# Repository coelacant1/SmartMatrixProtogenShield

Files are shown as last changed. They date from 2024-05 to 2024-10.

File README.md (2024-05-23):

# SmartMatrixProtogenShield
SmartMatrix SmartLED Shield breakout for Protogen hardware

## General Information
The SmartLED Shield for the Teensy 4 is used as the backbone to this design. This allows you to use open-source code to easily implement if you decide against using ProtoTracer to display graphics on your Protogen!

The following information is pulled directly from their Crowd Supply page as a means of maintaining a local copy in case they take the posting down:
[SmartLED Shield for Teensy 4](https://www.crowdsupply.com/pixelmatix/smartled-shield-for-teensy-4)

## Controller Breakout

### Information
The controller breakout provides sensor connectivity, power distribution, and indication methods for power.

## Bill of Materials

| **RefDes** | **Value** | **Footprint** | **Quantity** | **Description** |
|---|---|---|---|---|
| C1-C4 | 22µF | SMD 0805 | 4 | Power filtering capacitors |
| R1,R2,R5,R6 | 10KΩ | SMD 0805 | 4 | Pull-up resistors |
| R3,R4 | 470Ω | SMD 0805 | 2 | APA102 impedance matching resistors |
| LED1-2 | | SMD 0805 | 2 | Indicator LEDs. Type does not matter. |
| LEDPWR, BCKPWR | AMASS XT30U-F | Through-Hole  | 2 | Power in and out |
| I2C1-4 | JST S4B-XH-A  | Through-Hole  | 4 | I2C Devices |

## Power Setup

### Powering the Teensy 4.0 for Programming
For programming the Teensy 4.0, the bottom VIN from VUSB trace needs to be cut to not provide power to the LED boards and cause damage while programming.

### Powering the Controller for Usage
To use the controller, 5V must be provided to the XT30 connector. Make sure you follow the standards for the XT30 polarity!

## Sensors/Peripherals

### Boop Sensor (APDS-9960)
The APDS-9960 is a Time-of-Flight sensor that uses an IR light to measure the distance to the object in front of it using the I2C communication protocol. This can be connected on either the Teensy I2C breakout or the ESP32 I2C breakout. The following picture shows the recommended location for the device:

### MAX9814 Microphone
The MAX9814 electret microphone is a standard electret microphone with automatic gain compensation via an amplifier. This will pick up a varying range of sounds and not just your voice, so it is best to tune the software gain appropriately.

### Control Button
The control button is a simple button that allows you to toggle between faces. There is no analog filtering on the button with the kit as the button debouncing is handled in code within the ButtonHandler class.

### I2C OLED Display
The OLED display is a small display for mounting within the visor for the wearer to see. It is used to display the current face being displayed on the outside, status of a battery, or anything else you like. This will communicate over I2C with either the Teensy or the ESP32.

## Programming the Teensy

### Getting Started with ProtoTracer

#### Install Applications
- Install Visual Studio Code from here: [Visual Studio Code](https://code.visualstudio.com/)
- Install TeensyDuino from here: [TeensyDuino](https://www.pjrc.com/teensy/td_download.html)

#### Install Extensions
- Install PlatformIO IDE under the extensions in Visual Studio Code.
- Install C/C++ extension.

#### Download the Codebase
Download ProtoTracer from here: [ProtoTracer](https://github.com/coelacant1/ProtoTracer). You can use either the Zip download or clone it to a local Git repository.

## General Recommendations and Notes
- Do not use external power to the XT30 connector, unless it is 5V directly, the controller should be able to handle 4.5V to 5.5V but anything else is outside of specification.
- Do not short circuit the IO pins. Be careful about which pins are in use and are listed at the beginning of the guide.
- Be careful leaving the electronics in a humid environment.

## Images

### 3D View
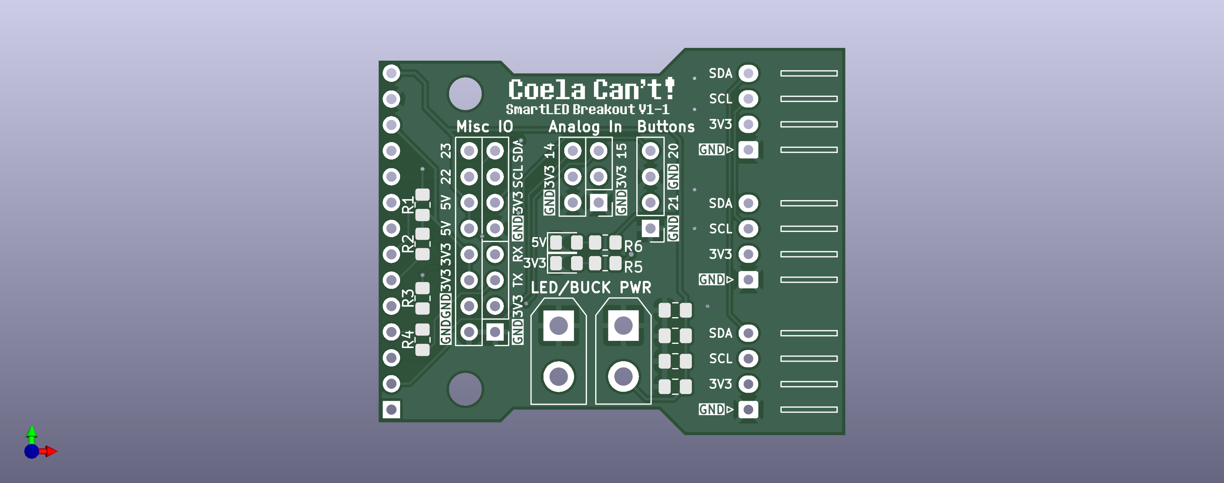
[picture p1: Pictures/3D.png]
3D View


### 3D View with Components
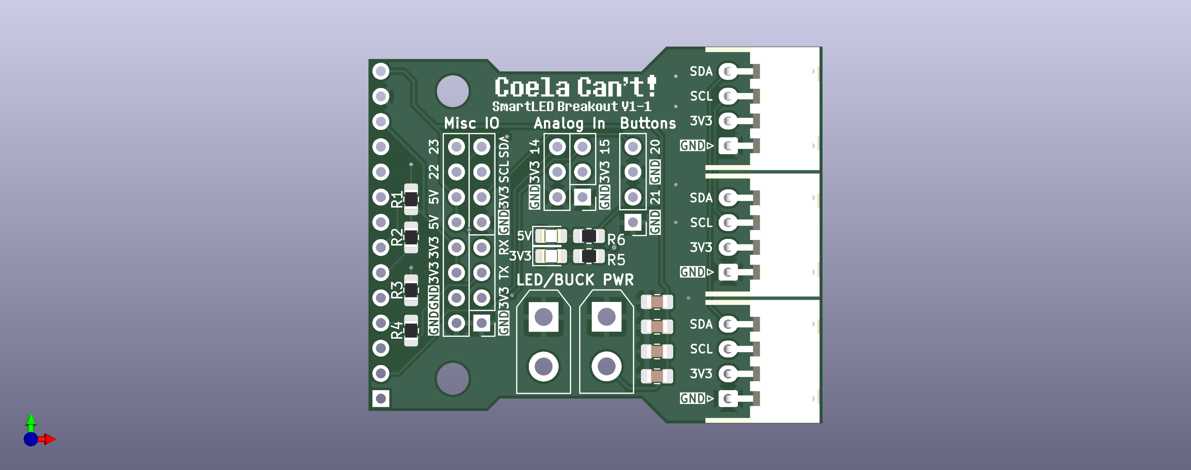
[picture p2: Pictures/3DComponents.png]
3D View with Components


### Layer View
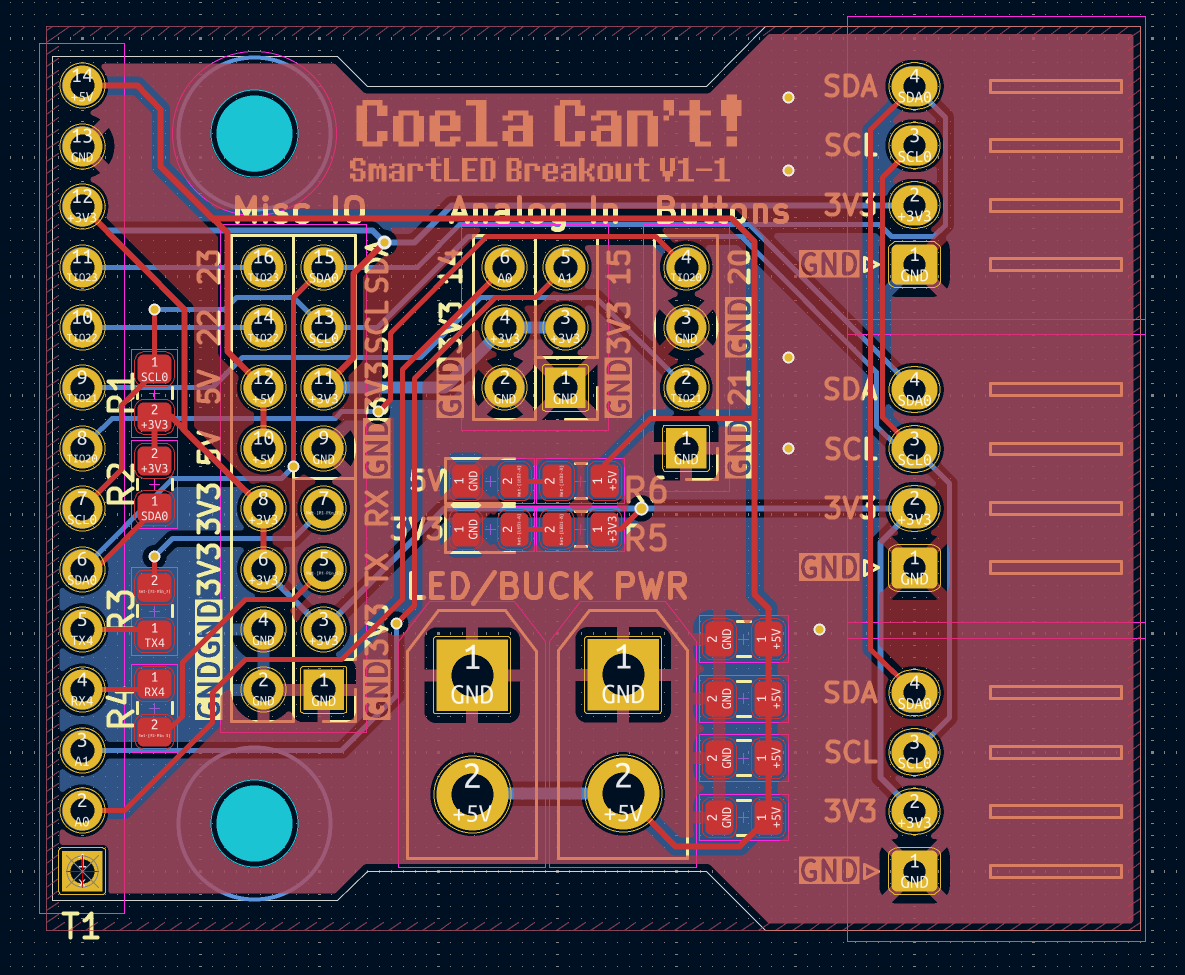
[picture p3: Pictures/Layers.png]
Layer View


### Electrical Schematic
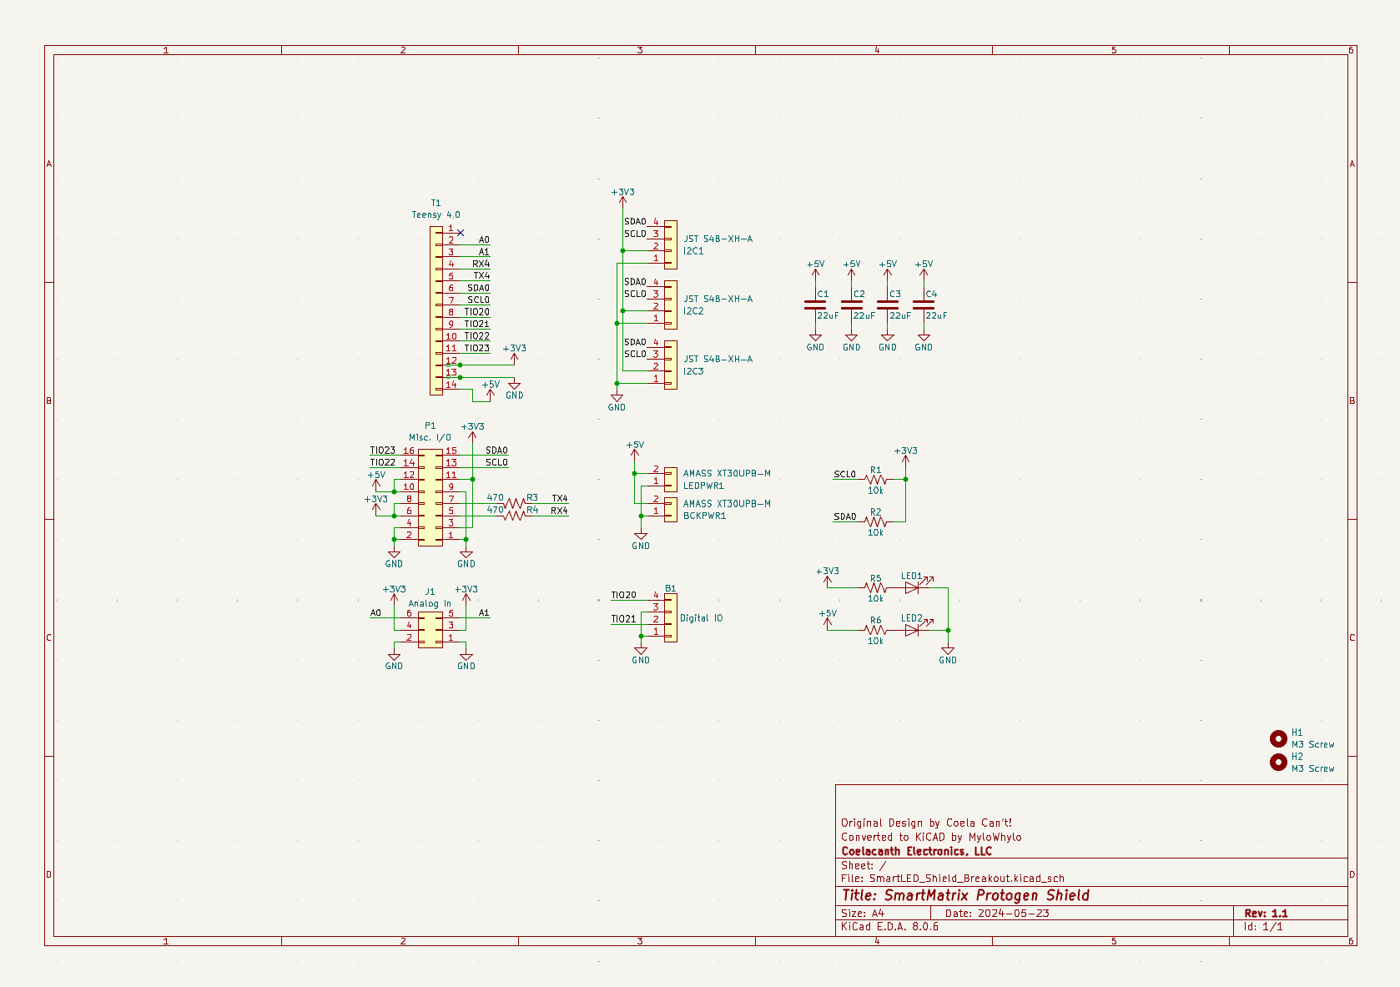
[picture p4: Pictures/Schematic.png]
Electrical Schematic


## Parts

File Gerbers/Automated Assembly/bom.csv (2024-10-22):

Designator | Footprint | Quantity | Value | LCSC Part #
BCKPWR1, LEDPWR1 | AMASS_XT30UPB-M_1x02_P5.0mm_Vertical | 2 | AMASS XT30UPB-M
C1, C2, C3, C4 | 0805 | 4 | 22uF
I2C1, I2C2, I2C3 | JST_XH_S4B-XH-A_1x04_P2.50mm_Horizontal | 3 | S4B-XH-A
LED1, LED2 | 0805 | 2 | LED
R1, R2, R5, R6 | 0805 | 4 | 10k
R3, R4 | 0805 | 2 | 470

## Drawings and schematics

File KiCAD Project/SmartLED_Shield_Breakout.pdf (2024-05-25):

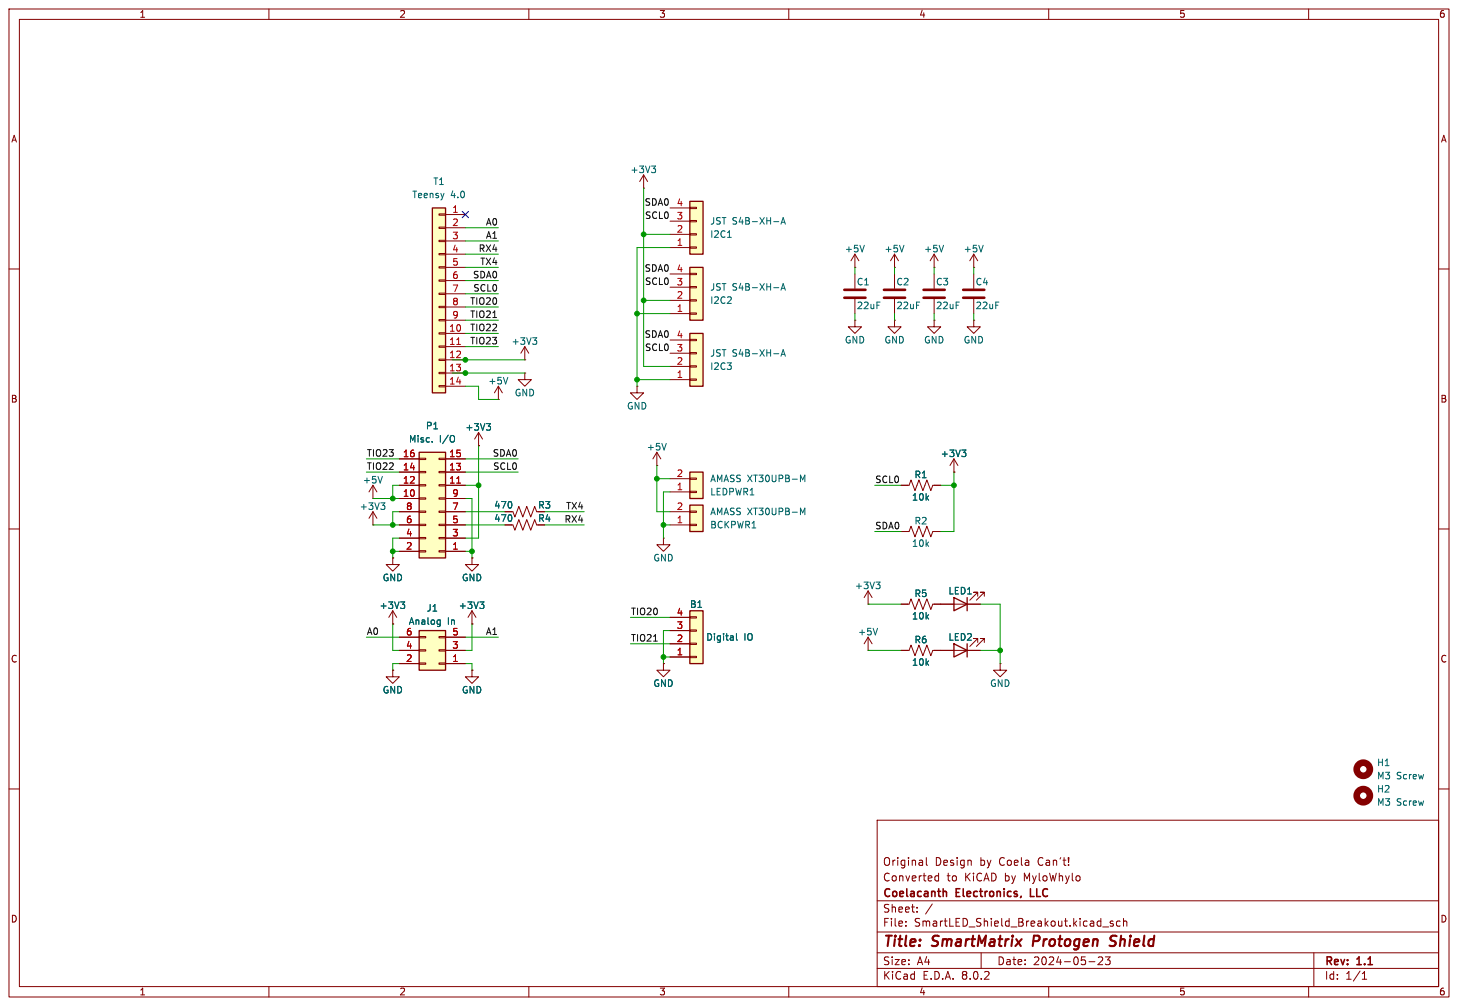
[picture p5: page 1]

Id: 1/1 Title: SmartMatrix Protogen Shield

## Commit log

2024-05-23 Add BOM to README.md
2024-05-24 add KiCAD version
    [SmartLED_Shield_Breakout.kicad_pcb, SmartLED_Shield_Breakout.kicad_sch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]
2024-10-18 Added hand solder & automated assembly gerbers for V1.1
    [SmartLED_Shield_Breakout.kicad_pcb, SmartLED_Shield_Breakout.kicad_sch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]
